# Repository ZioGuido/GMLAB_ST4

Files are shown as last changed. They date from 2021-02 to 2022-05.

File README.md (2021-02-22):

# GMLAB_ST4
Repository for GMLAB ST4 - Switchable Thru-box

ST4 is a "Four port Swtichable Thru Box", practically an easy and simple Midi Router, useful to control up to four synthesizers (or other MIDI devices) from one keyboard and switch quickly between them. Imagine you have one keyboard and up to four sound modules (synthesizers, drum machines, samplers, expanders, etc.) and you want to select which one you want to play from your keyboard. Just push the correspondent button and play, in any combination you like. The advantage of this box is that it will take into account notes still playing when the buttons are turned off, in order to avoid unwanted hung notes or incomplete Midi events. It can also function as a Usb-Midi interface.

Buy it in kit or preassembled at www.GMLAB.it

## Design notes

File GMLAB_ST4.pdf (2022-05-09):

## ST4 – SWITCHABLE MIDI THRU BOX

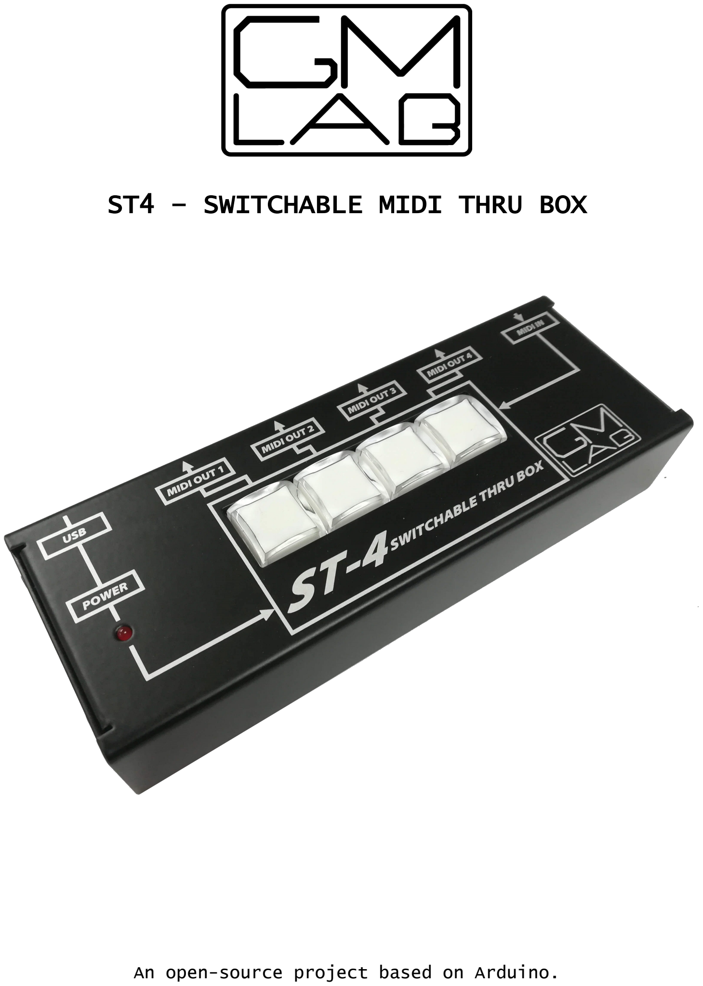
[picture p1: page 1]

An open-source project based on Arduino.

USER MANUAL

Congratulations, you are now the owner of ST4 switchable MIDI THRU BOX. Please read this manual in its entirety and keep it in a safe place for future reference. Have fun!

ST4 is a "Four port Swtichable Thru Box", practically an easy and simple Midi Router, useful to control up to four synthesizers (or other MIDI devices) from one keyboard and switch quickly between them. Imagine you have one keyboard and up to four sound modules (synthesizers, drum machines, samplers, expanders, etc.) and you want to select which one you want to play from your keyboard. Just push the correspondent button and play, in any combination you like. The advantage of this box is that it will take into account notes still playing when the buttons are turned off, in order to avoid unwanted hung notes or incomplete Midi events. It can also function as a Usb-Midi interface.

Use a 5V cellphone USB Charger/PSU to power ST4 and use MIDI ports to connect your instruments.

You can connect it with the provided USB Cable (well-known micro-USB for
cell | phones) | to | every | keyboards/expanders | able | to | recognize | class
compliant USB devices and you can take advantage of MIDI in thru that USB port.

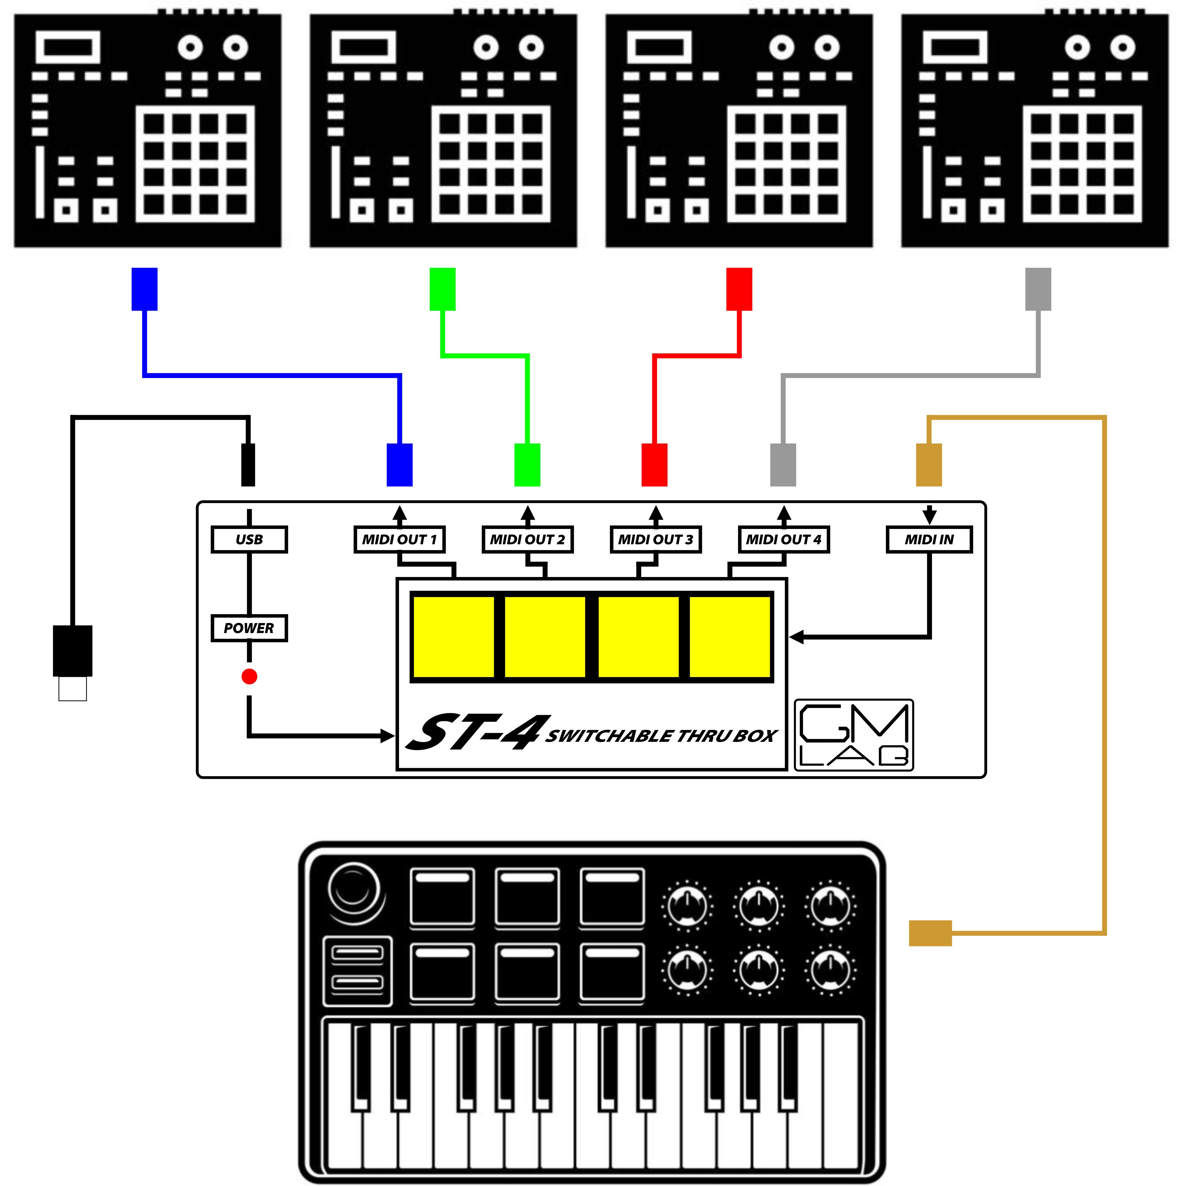
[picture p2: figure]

DIY KIT MOUNTING INSTRUCTIONS

Welcome to the mounting instruction sheet for the GMLAB ST4 switchable MIDI THRU BOX kit. To assemble this kit correctly and set it up to work properly, a certain skill with electronics, mechaninc and computers is required, plus some tools and a little bit of patience and attention.

REQUIRED TOOLS

1. Soldering iron, preferably a temperature-controlled 60W iron with a 1,5 ~ 2,5 mm wide tip;
2. Solder, preferably good quality 0,8 ~ 1 mm diameter;
3. Good quality cutters;
4. Phillips screwdriver;
5. A computer with Arduino IDE installed.

PREPARATION

Prepare a clean and tidy surface, with just the required tools handy and make sure you have discharged your body from electrostatic charge by touching some metal object that makes contact with the floor. Optionally, wear an ESD wristband.

WHAT'S IN THE KIT

- 1x PCB ST4 main board
- 1x PCB ST4 switches board
- 1x Arduino Pro Micro (Leonardo clone)
- 1x Metal bottom piece
- 1x Metal top cover
- 2x 220ohm resistors
- 1x 10k0hm resistor
- 1x 6n137 optocoupler
- 1x 74hc14n IC
- 1x 4066 IC
- 1x 220ohm 5pins polarized resistor net
- 1x 10kohm 5pins polarized resistor net
- 2x 220ohm 8pins resistor nets
- 1x 3mm red led with 18mm spacer
- 2x 100nF capacitors
- 4x illuminated switches
- 5x MAB DIN5 connectors
- 1x male long sil strip
- 4x m3x5 hex spacers MF
- 2x m3x10 hex spacers FF
- 8x m3x5 flat head screws
- 2x m3x5 pan head screws
- 2x m3 hex nuts
- 1x USB – MicroUSB cable
- 4x rubber feets

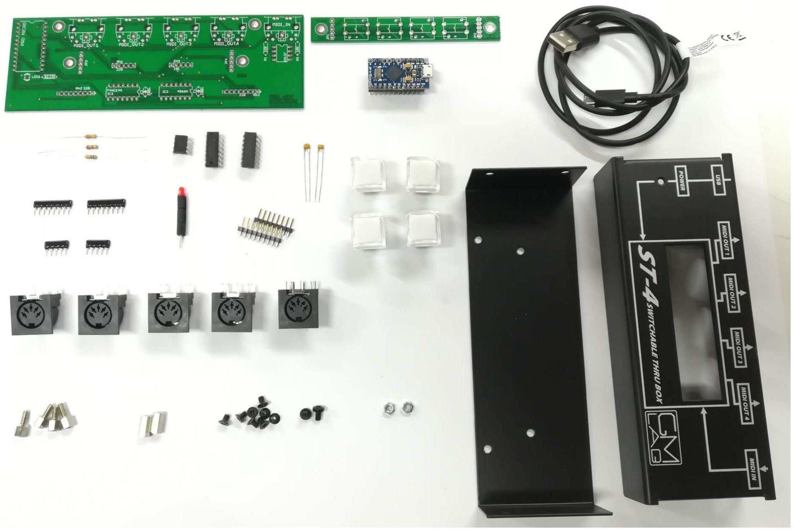
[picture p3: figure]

STEP 1: Let's start with ST4 mainboard from the passive components, from the lowest till the tallest. Take the resistors, bend the terminals 90 degrees and add them to the Main PCB in the correct positions (you can
check | the | schematics, | silkscreen | in | the | board | and | the | component
numbering). Do the same with the resistor networks and capacitors.

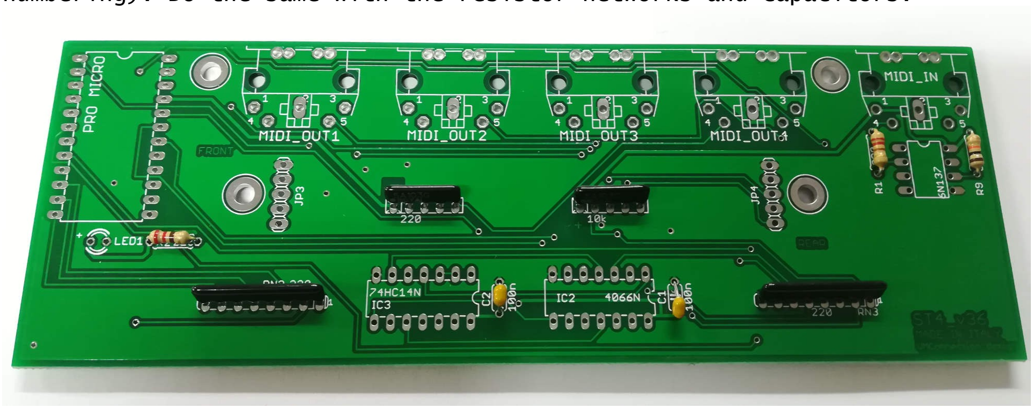
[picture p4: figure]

Note: the 5-pin resistors networks have a polarity: please pay attention to it. Polarity is marked with a white dot on the component itself, just match that dot with the pin in the circuit board marked with "+". The 8-pin resistors networks do not have any polarity.

STEP 2: Add all the integrated circuits. Pay attention not to keep the solder pin for too long, and that all pins have been soldered correctly. Do not solder two or more pins together, each pin is soldered separately. Also pay attention to the direction. Drawings on the PCB have a notch on a side indicating where pin 1 goes. The same notch is generally present on the IC itself, or you'll also find a small dot or a vertical line on the left side, where pin 1 is.

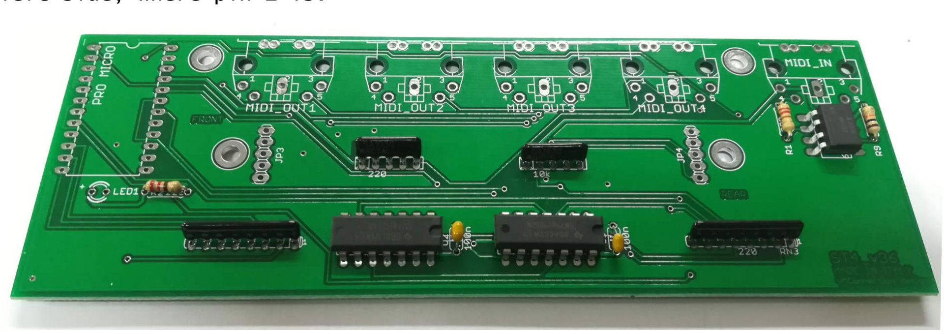
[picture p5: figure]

STEP 3: Mount the MIDI connectors and the LED with spacer. Refer to the image below.

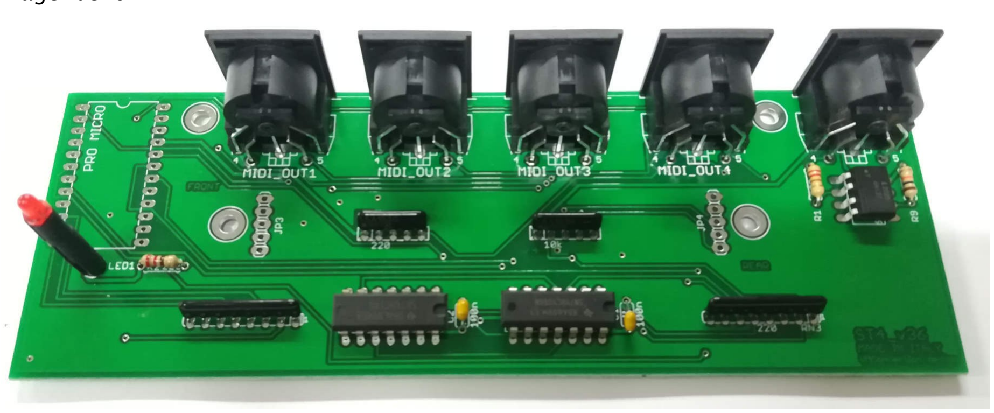
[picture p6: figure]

STEP 4: Add the the CPU board. Please note that the CPU comes pre-programmed with the default Arduino sketch and comes with all SIL terminals soldered.

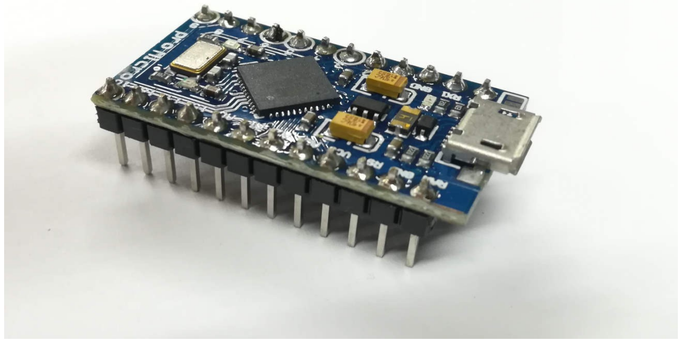
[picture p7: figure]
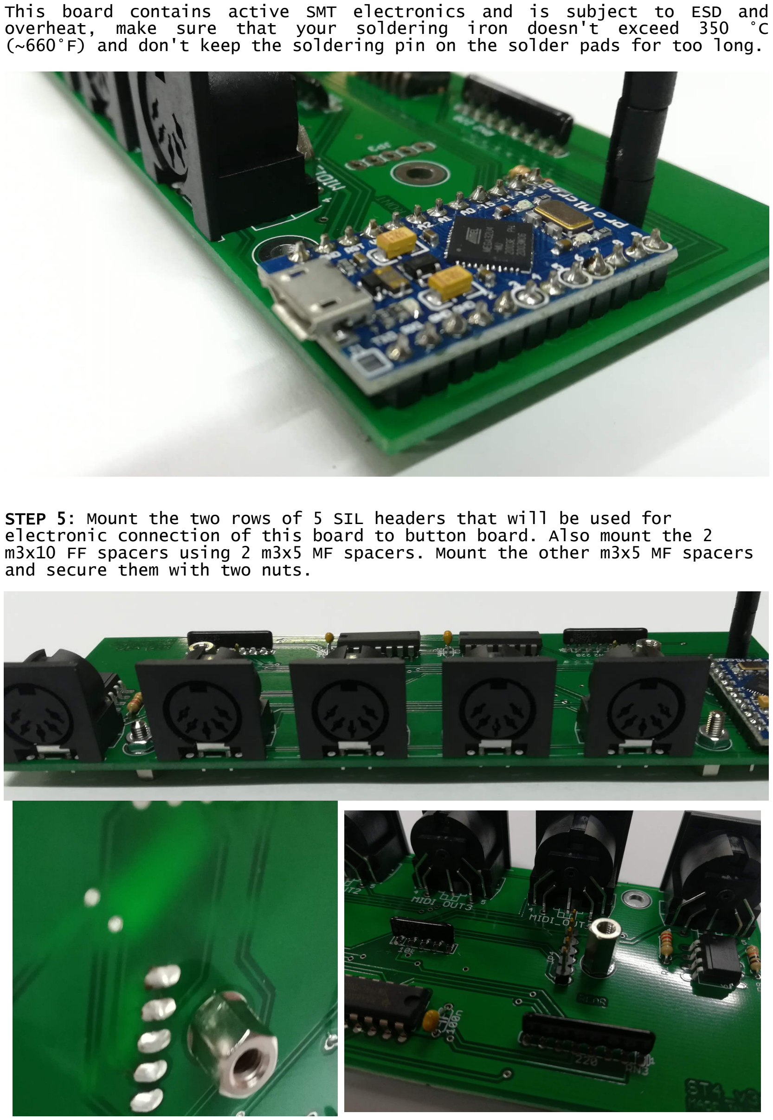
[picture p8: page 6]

This board contains active SMT electronics and is subject to ESD and overheat, make sure that your soldering iron doesn't exceed 350 °C (~660°F) and don't keep the soldering pin on the solder pads for too long.

STEP 5: Mount the two rows of 5 SIL headers that will be used for electronic connection of this board to button board. Also mount the 2 m3x10 FF spacers using 2 m3x5 MF spacers. Mount the other m3x5 MF spacers and secure them with two nuts.

STEP 6: Now it's time to assemble the button board: this is extremely simple because it only accomodates 4 illuminated buttons. But in the same time this board has something important to keep in mind. The first one is the position and polarity of the board: taking a look at it you will find labels reading "TOP", "REAR" and "FRONT": the bottom side is labeled "BOTTOM". Buttons need to be mounted on the "TOP" layer.

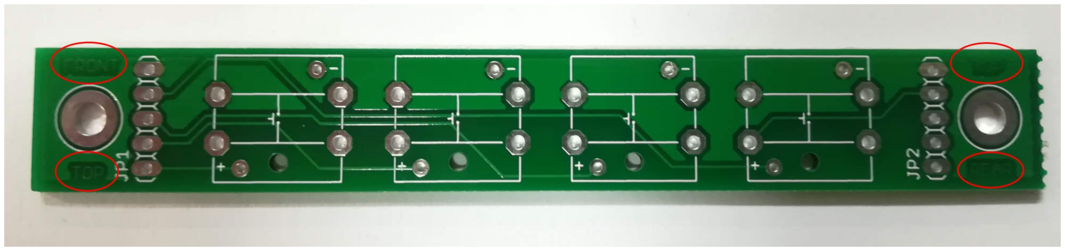
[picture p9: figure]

Second thing to keep in mind is the button polarity, they can enter and fully touch the surface of the board only if inserted correctly. There's a small ledge on the bottom of each button that has to fit the hole on the board. This indicates the right polarity for the buttons.

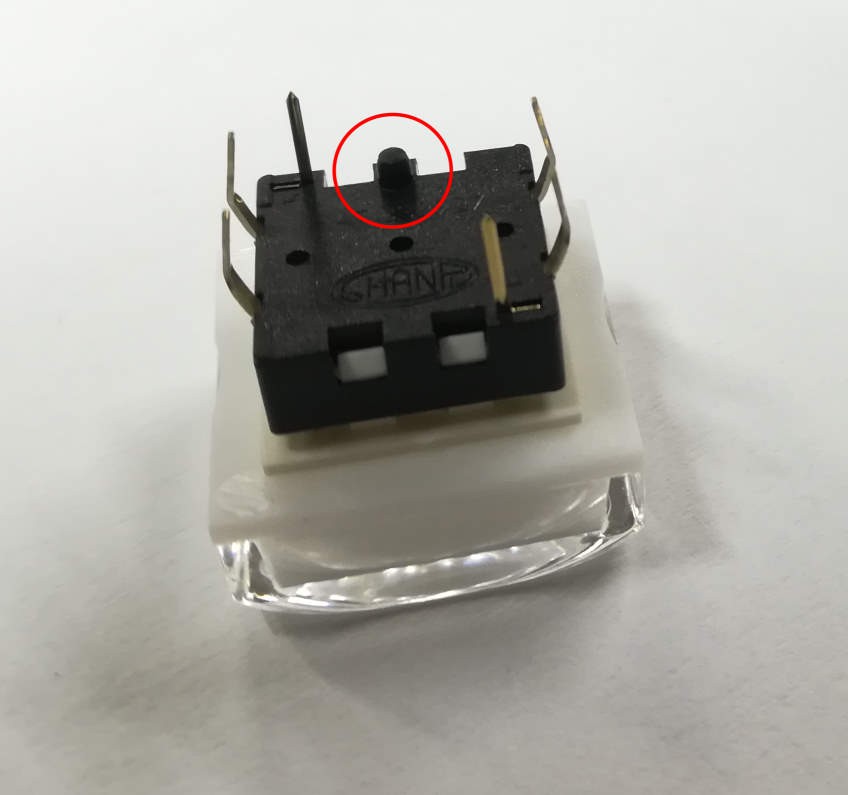
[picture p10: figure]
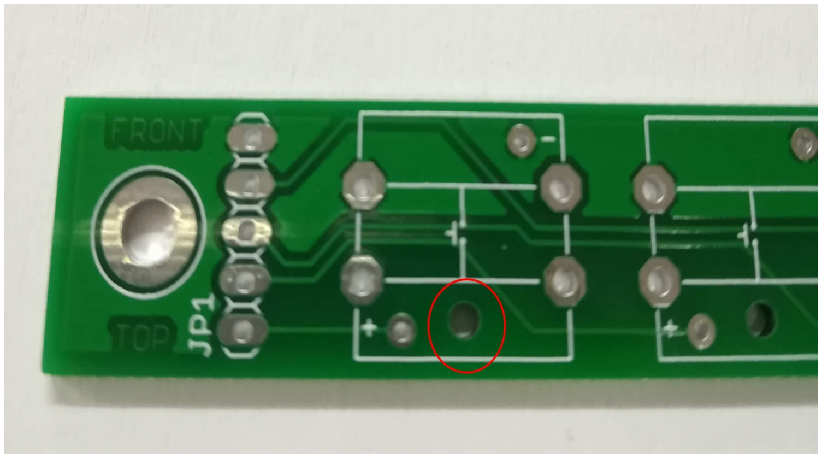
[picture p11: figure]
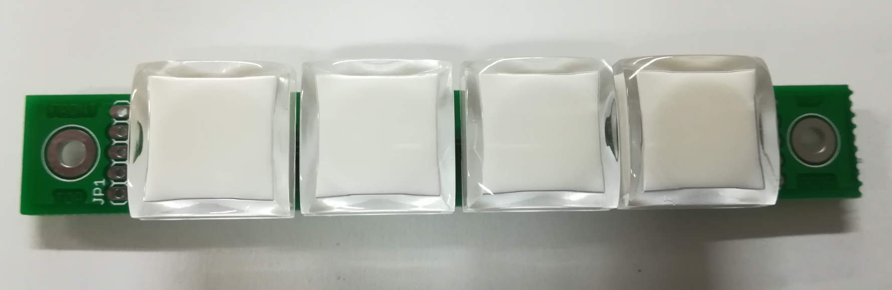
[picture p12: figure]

Once you are sure that all 4 buttons are well positioned, completely and evenly adherent to the board surface, you can solder them. Be careful with these switches, never pull them from the transparent upper dome or you will break them.

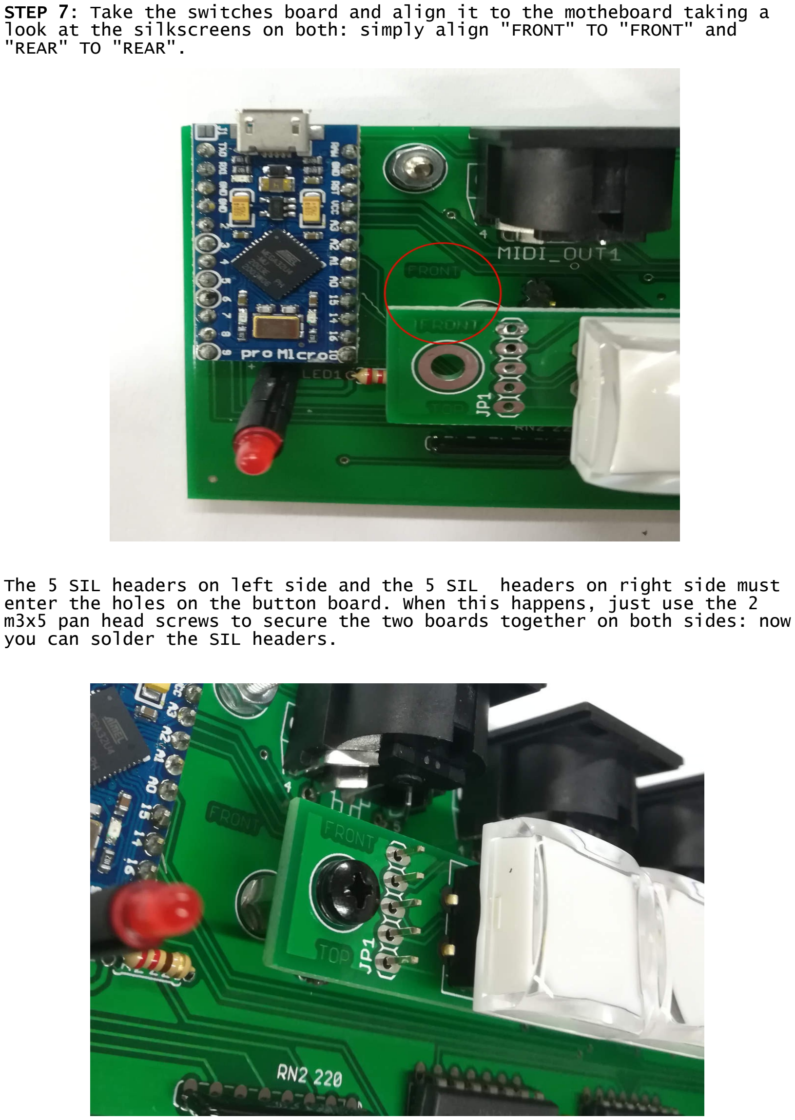
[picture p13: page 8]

STEP 7: Take the switches board and align it to the motheboard taking a look at the silkscreens on both: simply align "FRONT" TO "FRONT" and "REAR" TO "REAR".

The 5 SIL headers on left side and the 5 SIL headers on right side must enter the holes on the button board. When this happens, just use the 2 m3x5 pan head screws to secure the two boards together on both sides: now you can solder the SIL headers.

STEP 8: Mount the bottom metal piece aligning the 4 holes with the 4 m3x5
MF spacers and | PARTIALLY | screw on them 2 flat head m3x5 screws. Do not
completely thigten them otherwise you won't be able to go to next step.

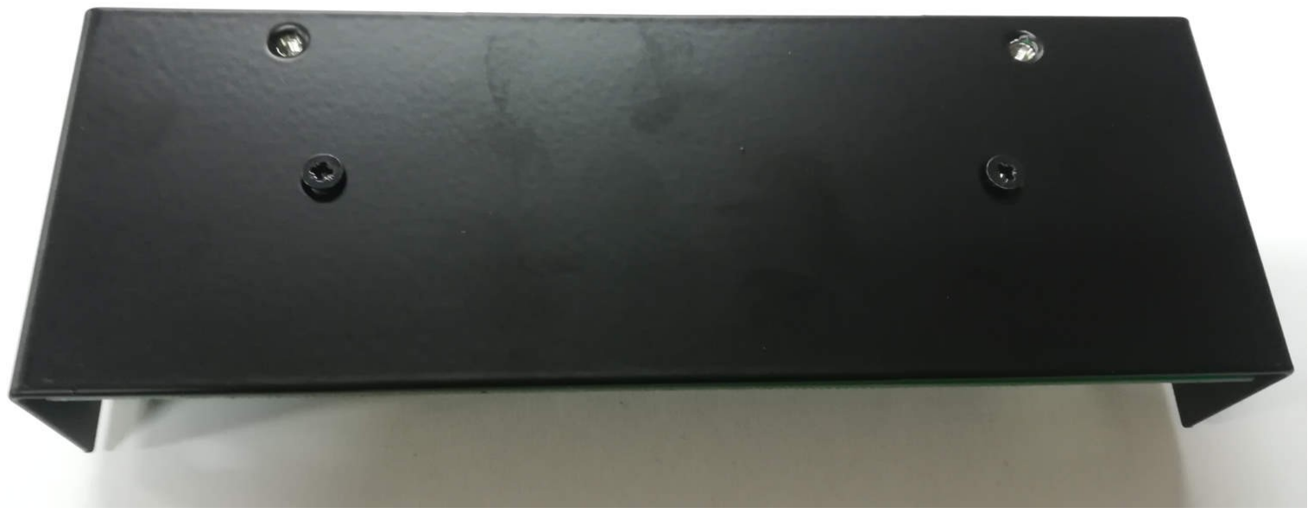
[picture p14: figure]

Now take to TOP and | GENTLY | slide it to the bottom assembly paying
attention to the LED and its hole in the metal top: note that the micro USB connector of the Arduino board is protruding the board, this is the reason why you have not completely fixed the ST4 board and the metal bottom: you need tolerance in order to let that connector fit its hole in the metal chassis.

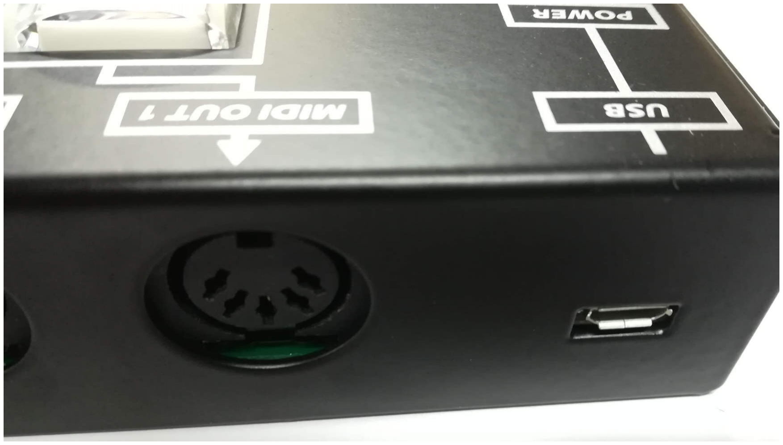
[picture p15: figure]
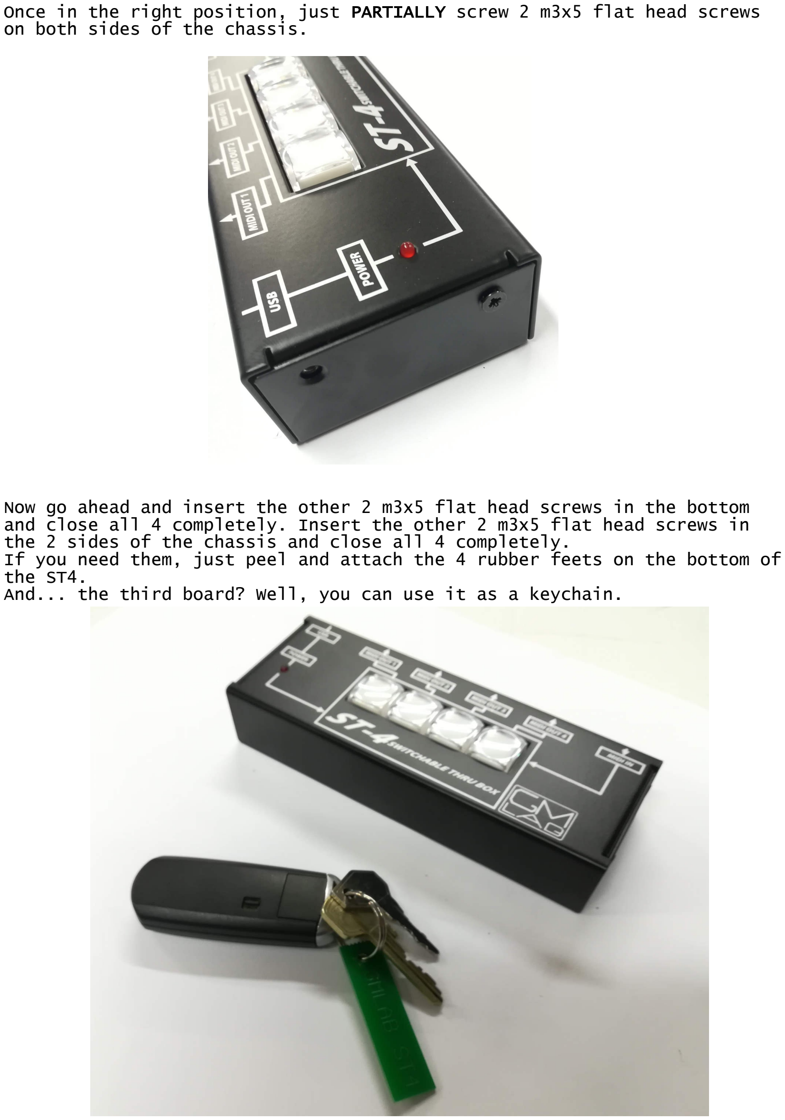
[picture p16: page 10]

Once in the right position, just | PARTIALLY | screw 2 m3x5 flat head screws
on both sides of the chassis.

Now go ahead and insert the other 2 m3x5 flat head screws in the bottom and close all 4 completely. Insert the other 2 m3x5 flat head screws in the 2 sides of the chassis and close all 4 completely.
If you need them, just peel and attach the 4 rubber feets on the bottom of the ST4.
And... the third board? Well, you can use it as a keychain.

PROGRAMMING THE CPU WITH ARDUINO

### PLASE NOTE: The Arduino board supplied with the ST4 comes pre-programmed with the default ST4 sketch. If you don't need to modify the source code yourself, you can skip this

whole section.

To program an Arduino board, you need a computer with Arduino IDE installed. Download it from the following URL:

https://www.arduino.cc/en/Main/Software

Install it on your computer following all the instructions given by the Arduino documentation.

If you haven't downloaded it yet, go to www.gmlab.it and download the Arduino sketch for the ST4 from the Document section.

PLEASE NOTE: before compiling the sketch, make sure you have installed the required libraries. The default sketch for the ST4 uses the following libraries (that should be installed separately using the IDE library functions, in case they aren't pre-installed):

– MIDI Library by Fourty Seven Effects -https://github.com/FortySevenEffects/arduino_midi_library Used to generate MIDI messages to be sent to the UART PORT

– MIDI-USB Library

– EEPROM (built-in) Used to store and recall the current status into the internal EEPROM

– MillisTimer by Brett Hagman - https://github.com/bhagman/MillisTimer Used to obtain two timers with millisecond precision

Connect the ST4 to your computer using the provided USB cable, start the IDE, load the sketch, then:

1. From the TOOLS menu, select BOARD -> Arduino Leonardo;
2. From the TOOLS menu, make sure the selected PORT points to Leonardo;
3. Click the icon with the arrow pointing right, this will compile the sketch and upload it to the board.

PLEASE NOTE: once the sketch is properly uploaded to the board, the USB port will not be seen by the IDE because it changes its function to USB-MIDI. To check that it is actually seen as a MIDI device, if you're using Windows (preferred), download and install the free application MIDI-OX and check that the ARDUINO MIDI device is listed among your MIDI ports, select it as an input port to MIDI-OX and check that it is correctly sending the expected CC messages.

An alternative to installing MIDI-OX is this quick and easy web-based MIDI Monitor utility (requires Chrome): https://www.gsidsp.com/midimonitor/

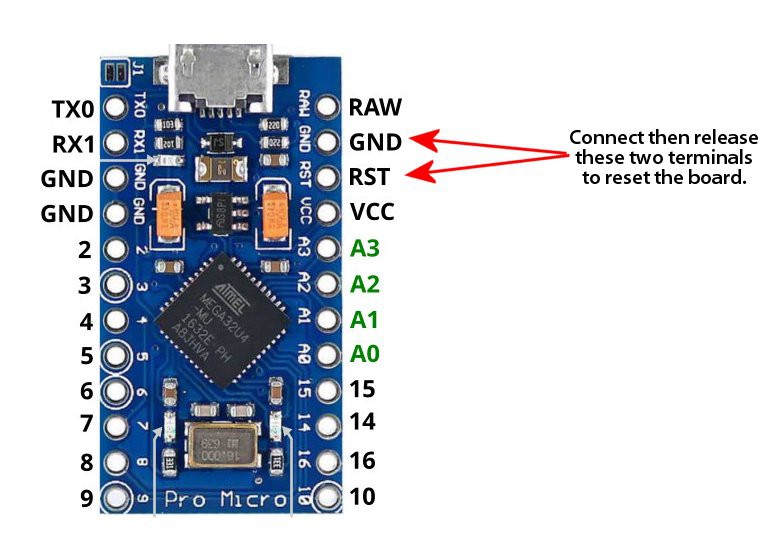
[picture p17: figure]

In case you need to
reprogram | the | board,
one | second | before
clicking | the | "LOAD"
icon | in | the | Arduino
IDE, | you | have | to
"reset" the board by
making | a | contact
between the terminals
labeled | RST | and | GND
using | a | small
screwdriver.

PLEASE NOTE: The has an internal button for the reset, you can push the button before starting to send the sketch to the board.

GMLAB ST4 | is sold on-line on the web sites | www.gmlab.it and on
www.MyRigShop.com by V.M.Connection, an enterprise based in Veneto, Italy.

Get the source code for this and other project on our GitHub account: https://github.com/ZioGuido

If you need spare parts or blank PCBs, just let us know.

All trademarks mentioned in this document belong to their respective owners and are used for reference purposes only.

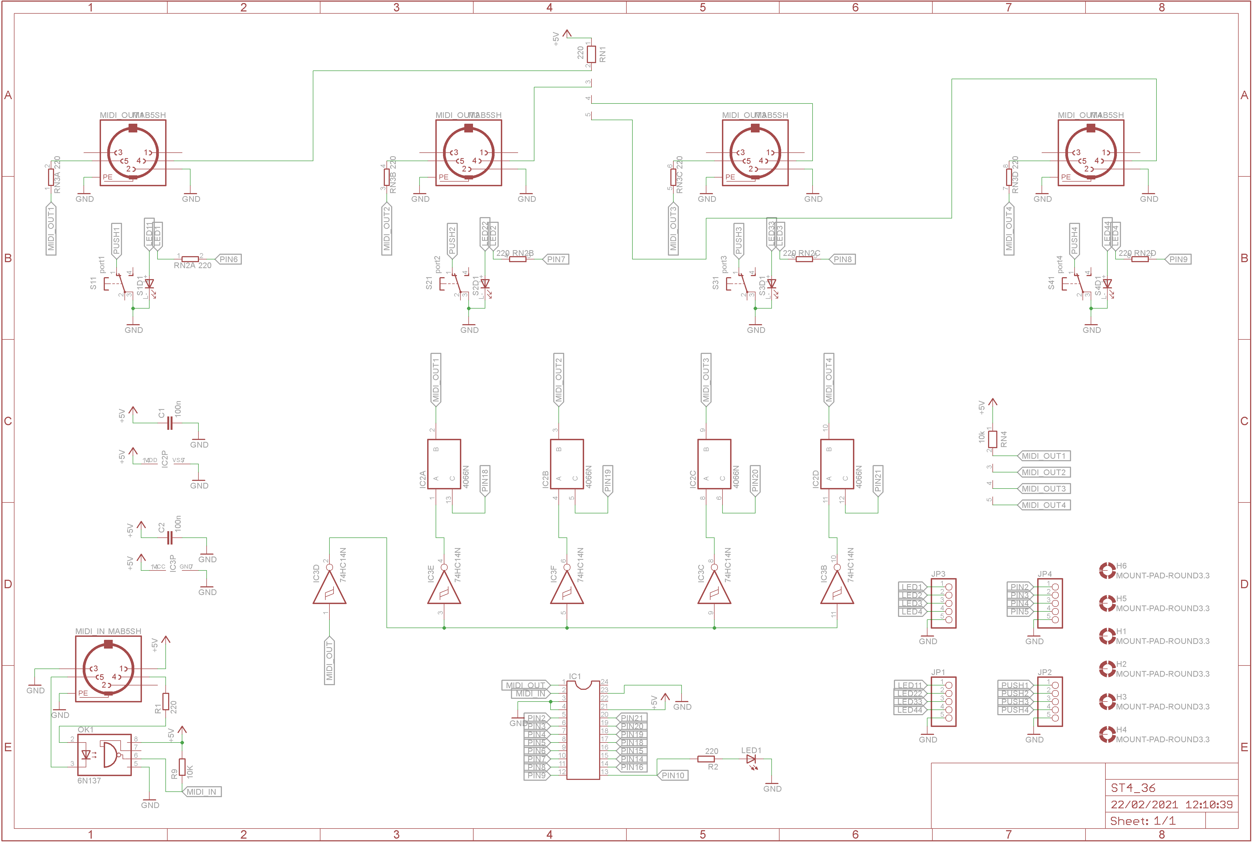
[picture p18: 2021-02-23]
Eagle/ST4.png

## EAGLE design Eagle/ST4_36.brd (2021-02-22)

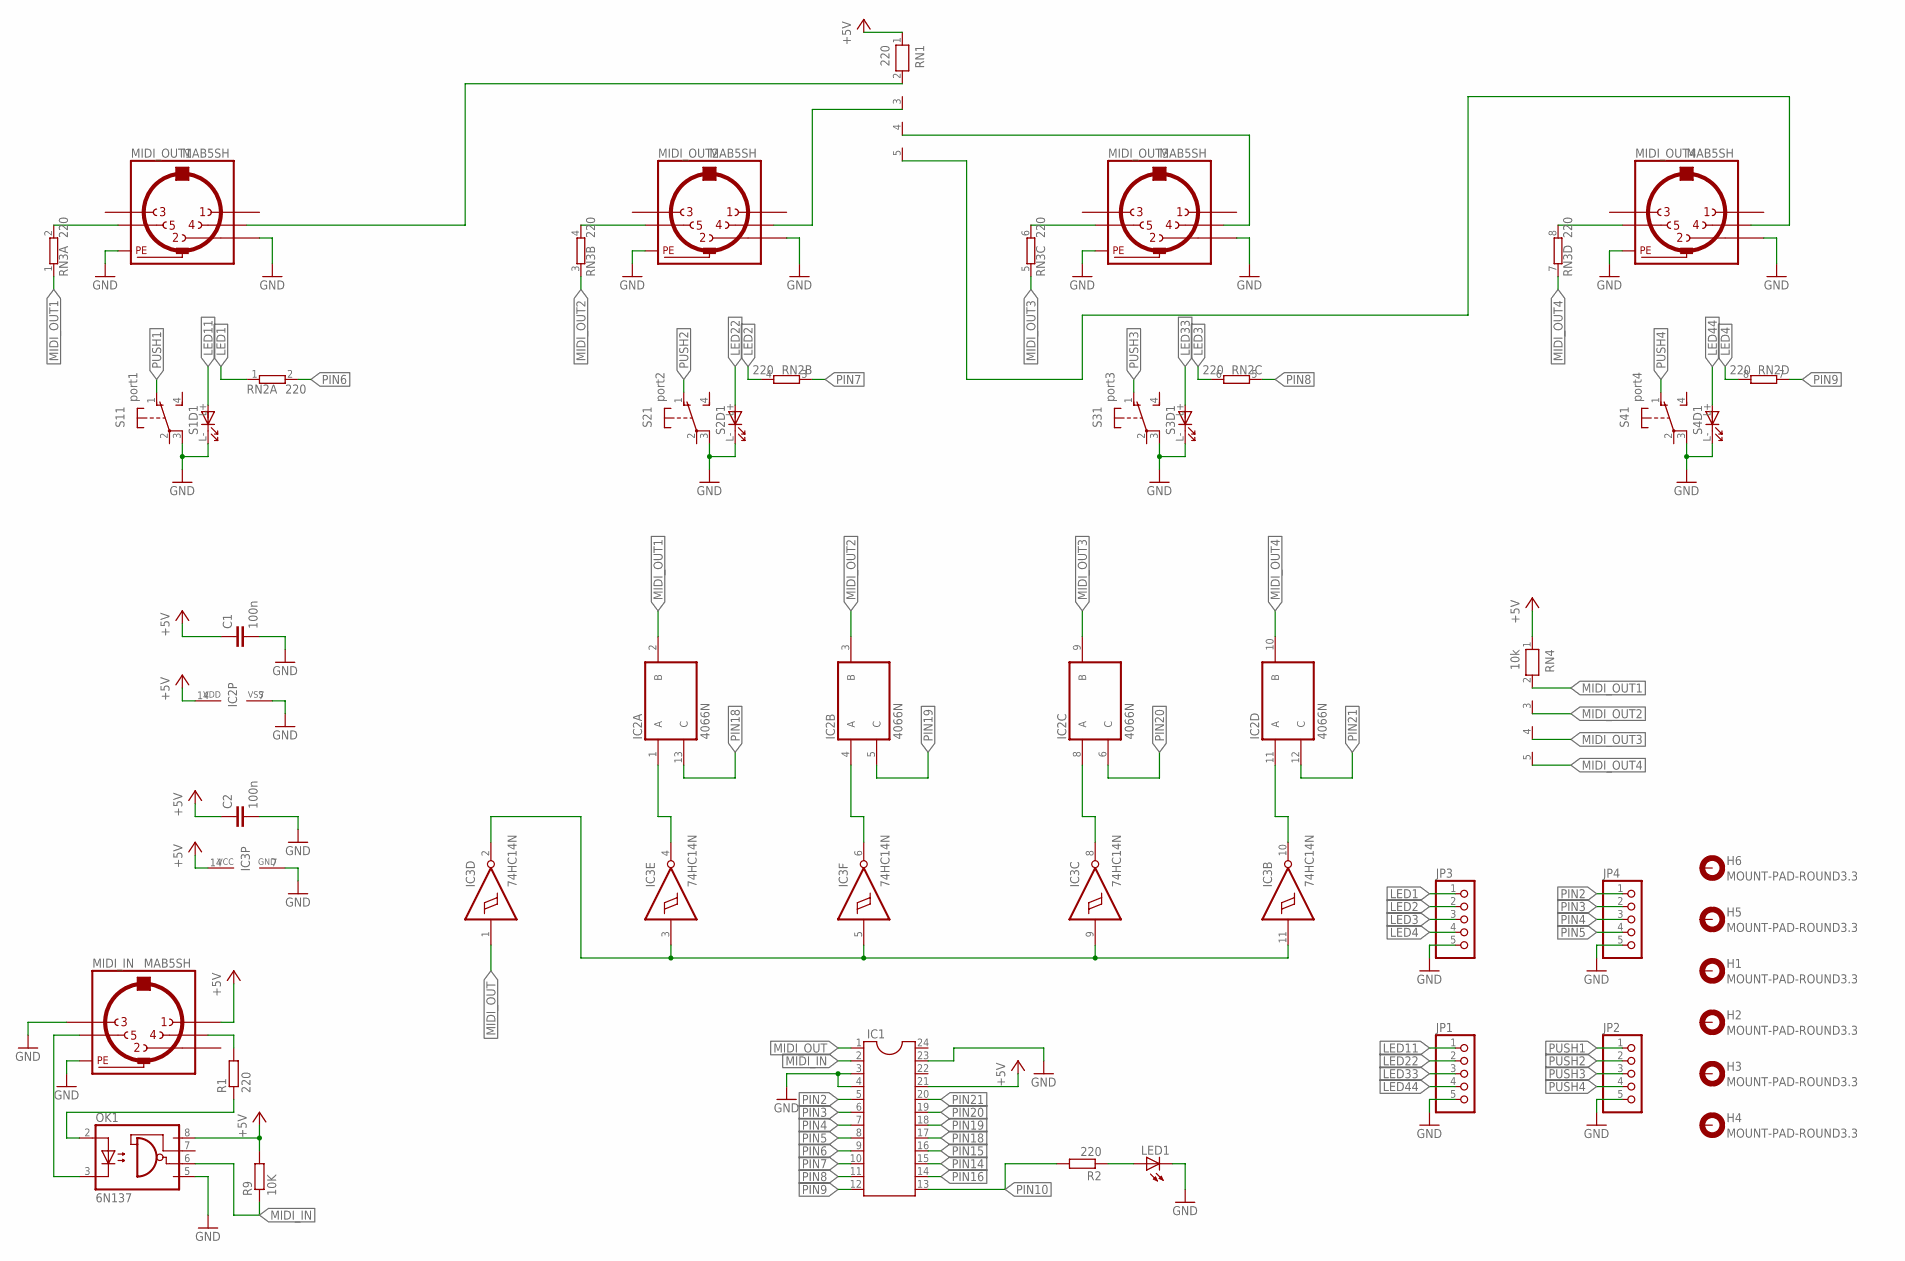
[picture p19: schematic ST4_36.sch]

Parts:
C1, C2: 100n; C050-024X044
H1, H2, H3, H4, H5, H6: MOUNT-PAD-ROUND3.3; 3,3-PAD
IC1: DIL24-6
IC2: 4066N; DIL14
IC3: 74HC14N; DIL14
JP1, JP2, JP3, JP4: PINHD-1X5; 1X05
LED1: LED_LED3MM
MIDI_IN: MAB5SH
MIDI_OUT1, MIDI_OUT2, MIDI_OUT3, MIDI_OUT4: MAB5SH
OK1: 6N137; DIL08
R1, R2: 220; 0207/7
R9: 10K; 0207/7
RN1: 220; RN-5
RN2, RN3: 220; SIL8
RN4: 10k; RN-5
S1: port1; SPLG1YCS0014
S2: port2; SPLG1YCS0014
S3: port3; SPLG1YCS0014
S4: port4; SPLG1YCS0014

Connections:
+5V: C1.1, C2.1, IC1.21, IC2.14 (VDD), IC3.14 (VCC), MIDI_IN.1, OK1.8 (VCC), R9.2, RN1.1, RN4.1
GND: C1.2, C2.2, IC1.3, IC1.4, IC1.23, IC2.7 (VSS), IC3.7 (GND), JP1.5, JP2.5, JP3.5, JP4.5, LED1.K (C), MIDI_IN.3, MIDI_IN.PE, MIDI_IN.PE@ (PE), MIDI_OUT1.2, MIDI_OUT1.PE, MIDI_OUT1.PE@ (PE), MIDI_OUT2.2, MIDI_OUT2.PE, MIDI_OUT2.PE@ (PE), MIDI_OUT3.2, MIDI_OUT3.PE, MIDI_OUT3.PE@ (PE), MIDI_OUT4.2, MIDI_OUT4.PE, MIDI_OUT4.PE@ (PE), OK1.5 (GND), S1.3, S1.L- (C), S2.3, S2.L- (C), S3.3, S3.L- (C), S4.3, S4.L- (C)
LED1: JP3.1, RN2.1
LED2: JP3.2, RN2.4 (2)
LED3: JP3.3, RN2.6 (2)
LED4: JP3.4, RN2.8 (2)
LED11: JP1.1, S1.L+ (A)
LED22: JP1.2, S2.L+ (A)
LED33: JP1.3, S3.L+ (A)
LED44: JP1.4, S4.L+ (A)
MIDI_IN: IC1.2, OK1.6 (VO), R9.1
MIDI_OUT: IC1.1, IC3.1 (I)
MIDI_OUT1: IC2.2 (B), RN3.1, RN4.2
MIDI_OUT2: IC2.3 (B), RN3.3 (1), RN4.3
MIDI_OUT3: IC2.9 (B), RN3.5 (1), RN4.4
MIDI_OUT4: IC2.10 (B), RN3.7 (1), RN4.5
unnamed: MIDI_OUT2.5, RN3.4 (2)
unnamed: MIDI_OUT3.5, RN3.6 (2)
unnamed: MIDI_OUT4.5, RN3.8 (2)
unnamed: MIDI_OUT4.4, RN1.5
unnamed: MIDI_IN.5, OK1.3 (C)
unnamed: OK1.2 (A), R1.1
unnamed: MIDI_IN.4, R1.2
unnamed: MIDI_OUT1.5, RN3.2
unnamed: MIDI_OUT2.4, RN1.3
unnamed: MIDI_OUT1.4, RN1.2
unnamed: MIDI_OUT3.4, RN1.4
unnamed: LED1.A, R2.1
unnamed: IC3.2 (O), IC3.3 (I), IC3.5 (I), IC3.9 (I), IC3.11 (I)
unnamed: IC2.1 (A), IC3.4 (O)
unnamed: IC2.4 (A), IC3.6 (O)
unnamed: IC2.8 (A), IC3.8 (O)
unnamed: IC2.11 (A), IC3.10 (O)
PIN2: IC1.5, JP4.1
PIN3: IC1.6, JP4.2
PIN4: IC1.7, JP4.3
PIN5: IC1.8, JP4.4
PIN6: IC1.9, RN2.2
PIN7: IC1.10, RN2.3 (1)
PIN8: IC1.11, RN2.5 (1)
PIN9: IC1.12, RN2.7 (1)
PIN10: IC1.13, R2.2
PIN14: IC1.15
PIN15: IC1.16
PIN16: IC1.14
PIN18: IC1.17, IC2.13 (C)
PIN19: IC1.18, IC2.5 (C)
PIN20: IC1.19, IC2.6 (C)
PIN21: IC1.20, IC2.12 (C)
PUSH1: JP2.1, S1.1 (O)
PUSH2: JP2.2, S2.1 (O)
PUSH3: JP2.3, S3.1 (O)
PUSH4: JP2.4, S4.1 (O)

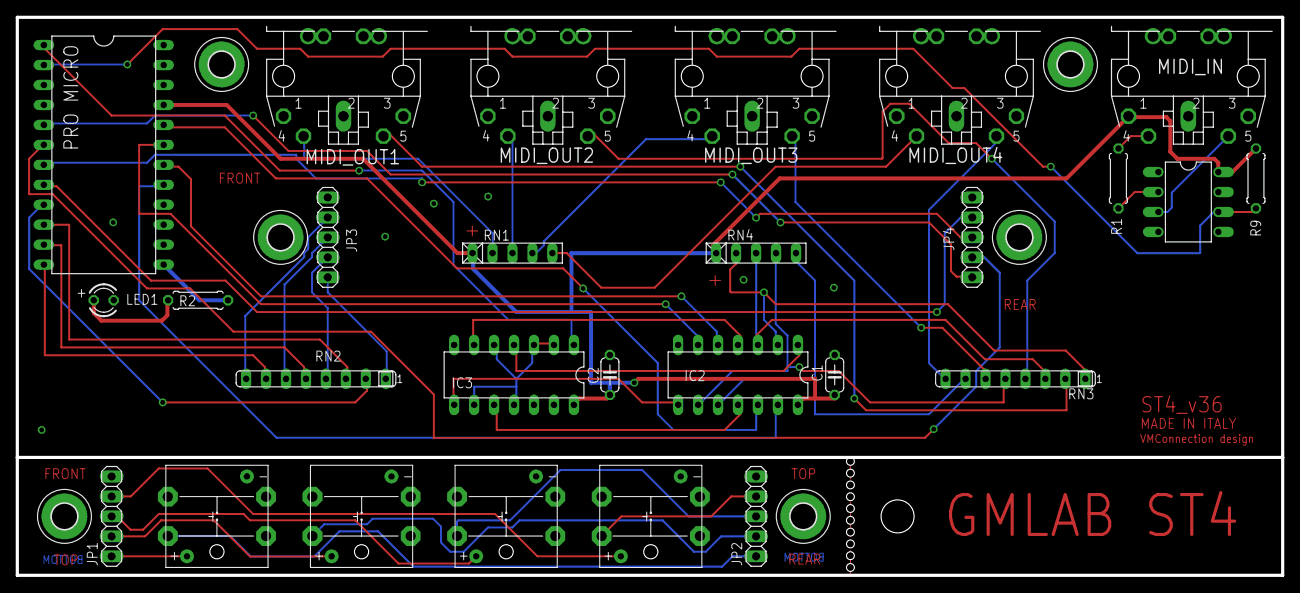
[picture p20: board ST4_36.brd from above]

Board: 2 copper layers, 161.0 x 71.0 mm, 33 parts (0 on the bottom side), 50 nets.

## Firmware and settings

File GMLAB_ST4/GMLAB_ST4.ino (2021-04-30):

//////////////////////////////////////////////////////////////////////////////////////////////////////////////////////
// Arduino sketch for the GMLAB ST4
// An open source Do-It-Yourself 4-PORT SWITCHABLE MIDI THRU BOX
// A THRU box that can turn output ports on or off in a safe way, using 4 illuminated buttons.
// Checks that a messages has been sent completely before turning off a port, and uses "Note Memory"
// that remembers a note-on events and sends the corresponding note-off event even after a port has been turned off,
// in order to prevent stuck notes.
//
// Applications: use this box to control up to 4 synthesizers/modules with one single controller/keyboard and 
// use the buttons to choose which unit to control.
//
// Code by Guido Scognamiglio - www.GenuineSoundware.com
// Start: Aug 2020 - Last update: Apr 2021
// 
// Runs on Arduino Leonardo or compatible boards (Atmel ATmega32U4)
// This sketch requires external libraries:
// - MIDI
// - MIDIUSB
// - MillsTimer
//

//////////////////////////////////////////////////////////////////////////////////////////////////////////////////////
// Pin definitions
//////////////////////////////////////////////////////////////////////////////////////////////////////////////////////

#define PIN_LED0  10
const char ButtonPins[4] = { 2, 3, 4, 5 };
const char ButtonLeds[4] = { 6, 7, 8, 9 };
const char MuxPins[4] = { 18, 19, 20, 21 };


//////////////////////////////////////////////////////////////////////////////////////////////////////////////////////
// Other useful definitions
//////////////////////////////////////////////////////////////////////////////////////////////////////////////////////

#define MIDI_STATUS_NOTEOFF           0x80  // b2=note, b3=velocity
#define MIDI_STATUS_NOTEON            0x90  // b2=note, b3=velocity
#define MIDI_STATUS_AFTERTOUCH        0xA0  // b2=note, b3=pressure
#define MIDI_STATUS_CONTROLCHANGE     0xB0  // b2=controller, b3=value
#define MIDI_STATUS_PROGRAMCHANGE     0xC0  // b2=program number
#define MIDI_STATUS_CHANNELPRESSURE   0xD0  // b2=pressure
#define MIDI_STATUS_PITCHBEND         0xE0  // pitch (b3 & 0x7f) << 7 | (b2 & 0x7f) and center=0x2000


//////////////////////////////////////////////////////////////////////////////////////////////////////////////////////
// External libraries
//////////////////////////////////////////////////////////////////////////////////////////////////////////////////////

#include <EEPROM.h>
#include <MIDI.h>
#include <MIDIUSB.h>
MIDI_CREATE_DEFAULT_INSTANCE();

#include "MillisTimer.h"  // This library creates a timer with millisecond precision
MillisTimer ButtonTimer;  // This is used for checking the buttons
MillisTimer ActivityTimer;  // Used to blink the Activity LED


//////////////////////////////////////////////////////////////////////////////////////////////////////////////////////
// Global variables
//////////////////////////////////////////////////////////////////////////////////////////////////////////////////////

char ButtonStatus[4] = { 1, 1, 1, 1 };

// This single variable will be used with bitshift operators so that one or more ports can be on or off
char PortStatus = 0; 
char USBPort = 0;

// Note Memory will store Channel and Port at Note On and reuse them at Note Off
struct NoteMemory
{
  char Status, Channel, Port;
};
NoteMemory NoteMem[128];
NoteMemory SustainPedal[16];


//////////////////////////////////////////////////////////////////////////////////////////////////////////////////////
// FUNCTIONS...
//////////////////////////////////////////////////////////////////////////////////////////////////////////////////////

// Called to send events to the USB Midi output (linked to OUT 1) // Note: MIDIUSB Library wants channels in range 0~15
void UsbMidiSend(byte b1, byte b2, byte b3)
{
  // USB output mirrors MIDI output #1
  if (!USBPort) return;
  
  byte Status  = b1 & 0xF0;
  byte Channel = b1 & 0x0F;
  midiEventPacket_t Event;
  Event = {Status >> 4, Status | Channel, b2, b3};
  MidiUSB.sendMIDI(Event);
  MidiUSB.flush();
}

// Pass the port variable that can either be the current PortStatus or an arbitrary port
void SetPort(char port)
{
  // Used to enable the USB Midi output linked to OUT 1
  USBPort = port & 1;
  
  // Switch ports
  for (int i=0; i<4; i++)
  {
    digitalWrite(MuxPins[i], (port >> i) & 1);
  }

  // Allow 10 uS for the MUX ports to stabilize
  delayMicroseconds(10);
}

void SwitchPorts(char pin)
{
  // Change bits with XOR operations
  switch (pin)
  {
  case 0: PortStatus ^= 1; break;
  case 1: PortStatus ^= 2; break;
  case 2: PortStatus ^= 4; break;
  case 3: PortStatus ^= 8; break;
  }

  // Set corresponding LED
  digitalWrite(ButtonLeds[pin], (PortStatus >> pin) & 1);
}

void DoButton(int btn, int status)
{
  if (ButtonStatus[btn] == status) return;
  ButtonStatus[btn] = status;

  // Things to do when a button is depressed
  if (status == LOW)
  {
    SwitchPorts(btn);
    EEPROM.update(8, PortStatus);
  }
}

void CheckButtons()
{
  for (int i=0; i<4; i++)
  {
    DoButton(i, digitalRead(ButtonPins[i]));
  }
}

void ActivityLed()
{
  digitalWrite(PIN_LED0, HIGH);
}

void setup() 
{
  // Turn on power LED
  pinMode(PIN_LED0, OUTPUT);
  ActivityLed();

  // Restore last state
  PortStatus = EEPROM.read(8);

  // Init I/Os
  for (int i=0; i<4; i++)
  {
    pinMode(ButtonPins[i], INPUT_PULLUP);
    pinMode(ButtonLeds[i], OUTPUT);
    pinMode(MuxPins[i], OUTPUT);
    digitalWrite(MuxPins[i], LOW);
    
    digitalWrite(ButtonLeds[i], (PortStatus >> i) & 1);
  }
  
  // Initialize the Note Memory
  for (int c=0; c<16; c++) // for each channel
  {
    SustainPedal[c].Status = 0;
    SustainPedal[c].Port = 0;
  }
    
  for (int n=0; n<128; n++) // for each note
  {
    NoteMem[n].Status = 0;
    NoteMem[n].Channel = 0;
    NoteMem[n].Port = 0;
  }

  // Set Timers
  ButtonTimer.setInterval(5);
  ButtonTimer.expiredHandler(CheckButtons);
  ButtonTimer.start();

  ActivityTimer.setInterval(10);
  ActivityTimer.setRepeats(1); // One-shot timer
  ActivityTimer.expiredHandler(ActivityLed);

  // Init the MIDI Library
  MIDI.begin(MIDI_CHANNEL_OMNI);  // Listen to all incoming messages
  MIDI.turnThruOff(); // Turn soft-thru off
}

void loop() 
{
  /////////////////////////////////////////////////////////////////////////////////////////////////////
  // Read incoming MIDI messages from USB-MIDI port
  midiEventPacket_t rx;
  do {
    rx = MidiUSB.read();
    if (rx.header != 0)
    {
      int Status  = rx.byte1  & 0xf0; // Event type
      int Channel = rx.byte1  & 0x0f; //

      // TO DO... (maybe forward USB messages to ports 2, 3 & 4 ?...
    }
  } while (rx.header != 0);
  

  /////////////////////////////////////////////////////////////////////////////////////////////////////
  // Read and process incoming MIDI messages
  if (MIDI.read())
  {
    // Start blinking Activity (Power) LED
    digitalWrite(PIN_LED0, LOW);
    ActivityTimer.start();

    switch (MIDI.getType())
    {
      case MIDI_STATUS_NOTEON:
        // Every time a NoteOn event is received, its status and port must be remembered
        NoteMem[MIDI.getData1()].Status = 1;
        NoteMem[MIDI.getData1()].Channel = MIDI.getChannel();
        NoteMem[MIDI.getData1()].Port = PortStatus;
        SetPort(PortStatus);
        MIDI.sendNoteOn(MIDI.getData1(), MIDI.getData2(), MIDI.getChannel());
        UsbMidiSend(MIDI_STATUS_NOTEON | MIDI.getChannel() - 1, MIDI.getData1(), MIDI.getData2());
        break;

      case MIDI_STATUS_NOTEOFF:
        // When a NoteOff is received, the message is only sent to its own port(s) if this note was on
        if (NoteMem[MIDI.getData1()].Status)
        {
          NoteMem[MIDI.getData1()].Status = 0; // reset status
          SetPort(NoteMem[MIDI.getData1()].Port); // set appropriate port (override current setting)
          MIDI.sendNoteOff(MIDI.getData1(), MIDI.getData2(), NoteMem[MIDI.getData1()].Channel);
          UsbMidiSend(MIDI_STATUS_NOTEOFF | NoteMem[MIDI.getData1()].Channel - 1, MIDI.getData1(), MIDI.getData2());
        }
        break;

      case MIDI_STATUS_CONTROLCHANGE:
        // In case of CC#64 (Sustain Pedal)...
        if (MIDI.getData1() == 64)
        {
          if (MIDI.getData2() > 63) 
          {
            SustainPedal[MIDI.getChannel() - 1].Status = 1;
            SustainPedal[MIDI.getChannel() - 1].Port = PortStatus;
            SetPort(PortStatus);
            MIDI.sendControlChange(64, 127, MIDI.getChannel());
            UsbMidiSend(MIDI_STATUS_CONTROLCHANGE | MIDI.getChannel() - 1,64, 127);
          }
          else
          {
            SustainPedal[MIDI.getChannel() - 1].Status = 0;
            SetPort(SustainPedal[MIDI.getChannel() - 1].Port);
            MIDI.sendControlChange(64, 0, MIDI.getChannel());
            UsbMidiSend(MIDI_STATUS_CONTROLCHANGE | MIDI.getChannel() - 1, 64, 0);
          }
          
          break;
        }
        
        SetPort(PortStatus);
        MIDI.sendControlChange(MIDI.getData1(), MIDI.getData2(), MIDI.getChannel());
        UsbMidiSend(MIDI_STATUS_CONTROLCHANGE | MIDI.getChannel() - 1, MIDI.getData1(), MIDI.getData2());
        break;

      case MIDI_STATUS_PROGRAMCHANGE:
        SetPort(PortStatus);
        MIDI.sendProgramChange(MIDI.getData1(), MIDI.getChannel());
        UsbMidiSend(MIDI_STATUS_PROGRAMCHANGE | MIDI.getChannel() - 1, MIDI.getData1(), MIDI.getData2());
        break;

      case MIDI_STATUS_CHANNELPRESSURE:
        SetPort(PortStatus);
        MIDI.sendAfterTouch(MIDI.getData1(), MIDI.getChannel());
        UsbMidiSend(MIDI_STATUS_CHANNELPRESSURE | MIDI.getChannel() - 1, MIDI.getData1(), MIDI.getData2());
        break;

      case MIDI_STATUS_PITCHBEND:
        SetPort(PortStatus);
        // 14 bit to dec (-8192 ~ 8192), center = 0
        MIDI.sendPitchBend((MIDI.getData1() + (MIDI.getData2() << 7) - 8192), MIDI.getChannel());
        UsbMidiSend(MIDI_STATUS_PITCHBEND | MIDI.getChannel() - 1, MIDI.getData1(), MIDI.getData2());
        break;
    }
  }

  // Run Timers
  ButtonTimer.run();
  ActivityTimer.run();
}
